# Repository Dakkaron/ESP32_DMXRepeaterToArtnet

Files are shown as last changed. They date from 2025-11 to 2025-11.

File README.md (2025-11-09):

# ESP32_DMXRepeaterToArtnet
A small DMX repeater and Artnet over Wifi transmitter

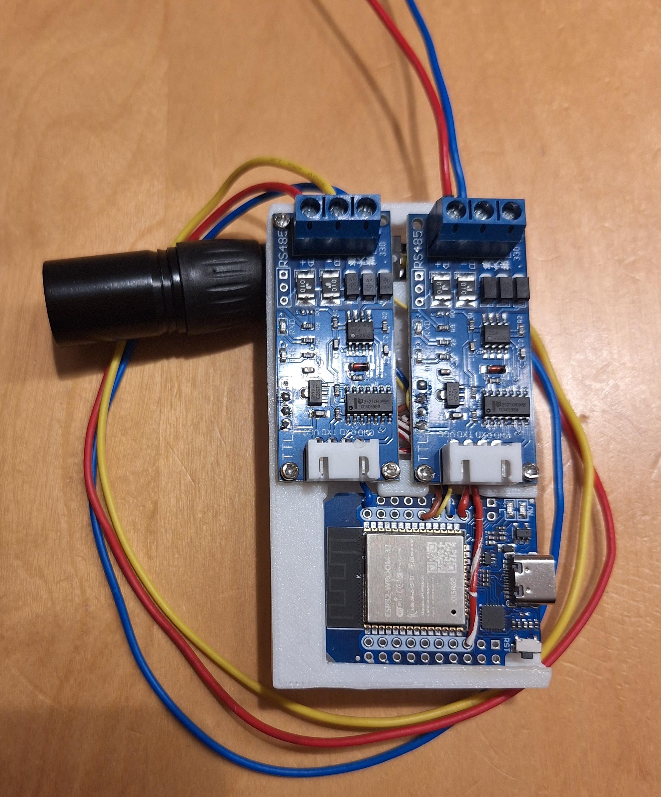
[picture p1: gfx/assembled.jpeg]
Image showing the finished device


Disclaimer: This is not a polished project. This is a quick-and-dirty project that I made for my own needs. Feel free to replicate it, but your milage may vary.

# BOM
- Wemos D1 Mini ESP32 development board
- 2x Max485 breakout boards. I used [these ones here](https://de.aliexpress.com/item/1005007383346753.html). Others would likely work too, but different dimensions could make mounting them more difficult. If you choose an alternative one, make sure it has
  - Three pins for DMX (GND, D- and D+). Many don't have the GND pin, you should have it
  - 3.3V support so it can run on the same voltage as the ESP32
  - Mine only has RX and TX pins as output. If yours has pins like DE or OE, you need to adjust the schematic/code for that
- 3D printed base plate
- 3D printed Din Rail mounting tab (only necessary for DIN Rail mounting)
- Optional: L78S05CV power regulator to allow this to be powered with 7-35V input

# How to wire it up

## L78S05CV

- Use shrinkwrap around the legs that you solder to to avoid any shorts
- Vin to external power supply VCC
- GND to external power supply GND, and to any GND pin on the ESP32
- Vout to VCC pin on the ESP32

## Left Max485 breakout board

- Solder all these connections from the **bottom** of the breakout board
- Vin to 3.3V pin on the ESP32
- GND to any GND pin on the ESP32
- RX to ESP32 pin 16, and to TX of right Max485 breakout board
- Optionally: TX to ESP32 pin 17, and to RX of right Max485 breakout board. This could be used for RDM, but I haven't tested this and I cannot guarantee for anything.

## Right Max485 breakout board

- Solder all these connections from the **bottom** of the breakout board
- Vin to 3.3V pin on the ESP32
- GND to any GND pin on the ESP32
- connect RX and TX as described above

## ESP32

- Solder all these connections from the **top** of the development board
- Connect all connections as described above

# How to assemble it

- Put the L78S05CV into the hole at the top of the assembly. Route the two cables that go to the external power supply through the provided hole at the top. Screw the L78S05CV into the back plate
- Slide the ESP32 into the slot at the bottom from the side. If the tolerances are too tight, you might need to use a file to make the slot a little bigger.
- Sort in all the wires into the space below where the Max485 boards go, and screw the two boards in so that they cover all the wries in behind.

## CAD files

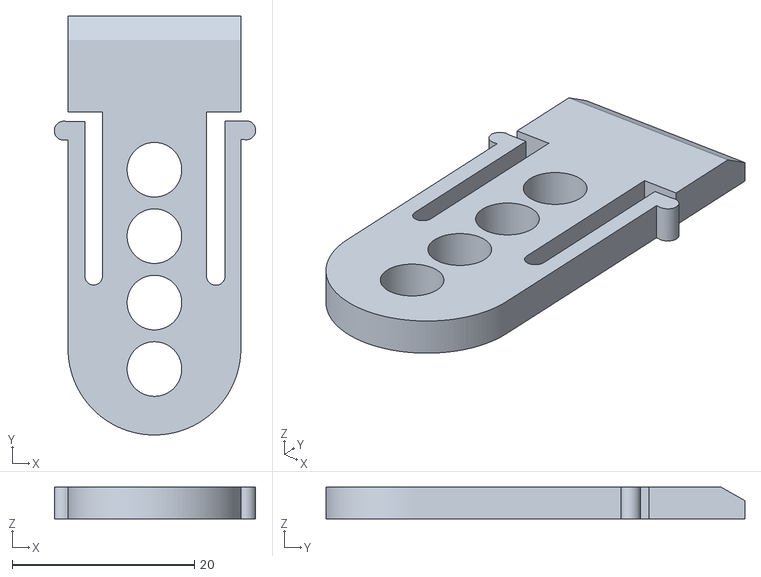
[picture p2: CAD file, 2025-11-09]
3dprint/Din_Rail_Mounting_tab_V4.stl
22.1 x 46.0 x 3.50

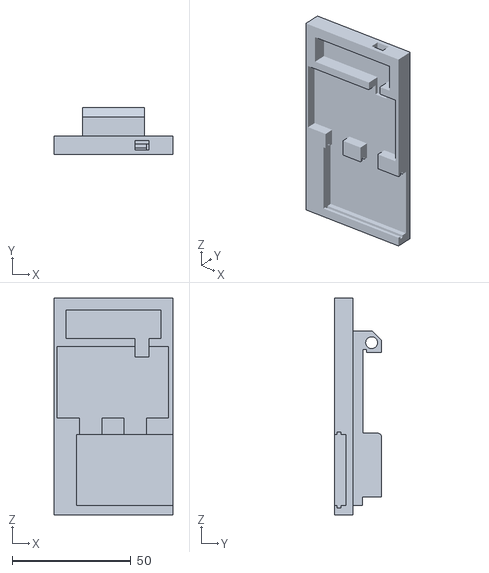
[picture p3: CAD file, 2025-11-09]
3dprint/DinRailESP32Max485.stl
50.0 x 20.0 x 91.5

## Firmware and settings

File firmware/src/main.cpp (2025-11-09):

#include <ArtnetWifi.h>
#include <Arduino.h>
#include <esp_dmx.h>

//#define DEBUGLOG_ENABLED

const char* ssid = "SSID";
const char* password = "PASSWORD";

ArtnetWifi artnet;
const int startUniverse = 1;
const char host[] = "192.168.0.55";

int transmitPin = 17;
int receivePin = 16;
int enablePin = 21;

dmx_port_t dmxPort = 1;

byte data[DMX_PACKET_SIZE];

bool dmxIsConnected = false;
unsigned long lastUpdate = millis();


bool ConnectWifi(void) {
  bool state = true;
  int i = 0;

  WiFi.begin(ssid, password);
  Serial.println("");
  Serial.println("Connecting to WiFi");
  
  Serial.print("Connecting");
  while (WiFi.status() != WL_CONNECTED) {
    delay(500);
    Serial.print(".");
    if (i > 20){
      state = false;
      break;
    }
    i++;
  }
  if (state){
    Serial.println("");
    Serial.print("Connected to ");
    Serial.println(ssid);
    Serial.print("IP address: ");
    Serial.println(WiFi.localIP());
  } else {
    Serial.println("");
    Serial.println("Connection failed.");
  }
  
  return state;
}

void setupDMX() {
  dmx_config_t config = DMX_CONFIG_DEFAULT;
  dmx_personality_t personalities[] = {
    {1, "Default Personality"}
  };
  int personality_count = 1;
  dmx_driver_install(dmxPort, &config, personalities, personality_count);

  dmx_set_pin(dmxPort, transmitPin, receivePin, enablePin);
}

void setup() {
  Serial.begin(115200);
  setupDMX();

  ConnectWifi();
  artnet.begin(host);
  artnet.setLength(192);
  artnet.setUniverse(startUniverse);
}

void loop() {
  dmx_packet_t packet;

  if (dmx_receive(dmxPort, &packet, DMX_TIMEOUT_TICK)) {
    unsigned long now = millis();

    if (!packet.err) {
      if (!dmxIsConnected) {
        Serial.println("DMX is connected!");
        dmxIsConnected = true;
      }

      dmx_read(dmxPort, data, packet.size);

      #ifdef DEBUGLOG_ENABLED
        Serial.printf("Start code is 0x%02X and slot 1 is 0x%02X, size: %u\n", data[0],
                    data[1], packet.size);
      #endif
      lastUpdate = now;
      #ifdef DEBUGLOG_ENABLED
        Serial.print("Sending artnet ...");
      #endif
      for (uint32_t i=0;i<192;i++) {
        artnet.setByte(i, data[i+1]);
      }
      #ifdef DEBUGLOG_ENABLED
        Serial.print("go ...");
      #endif
      artnet.write();
      #ifdef DEBUGLOG_ENABLED
        Serial.println("Done");
      #endif
    } else {
      Serial.println("A DMX error occurred.");
    }
  } else if (dmxIsConnected) {
    Serial.println("DMX was disconnected, reconnecting.");
  }
}
